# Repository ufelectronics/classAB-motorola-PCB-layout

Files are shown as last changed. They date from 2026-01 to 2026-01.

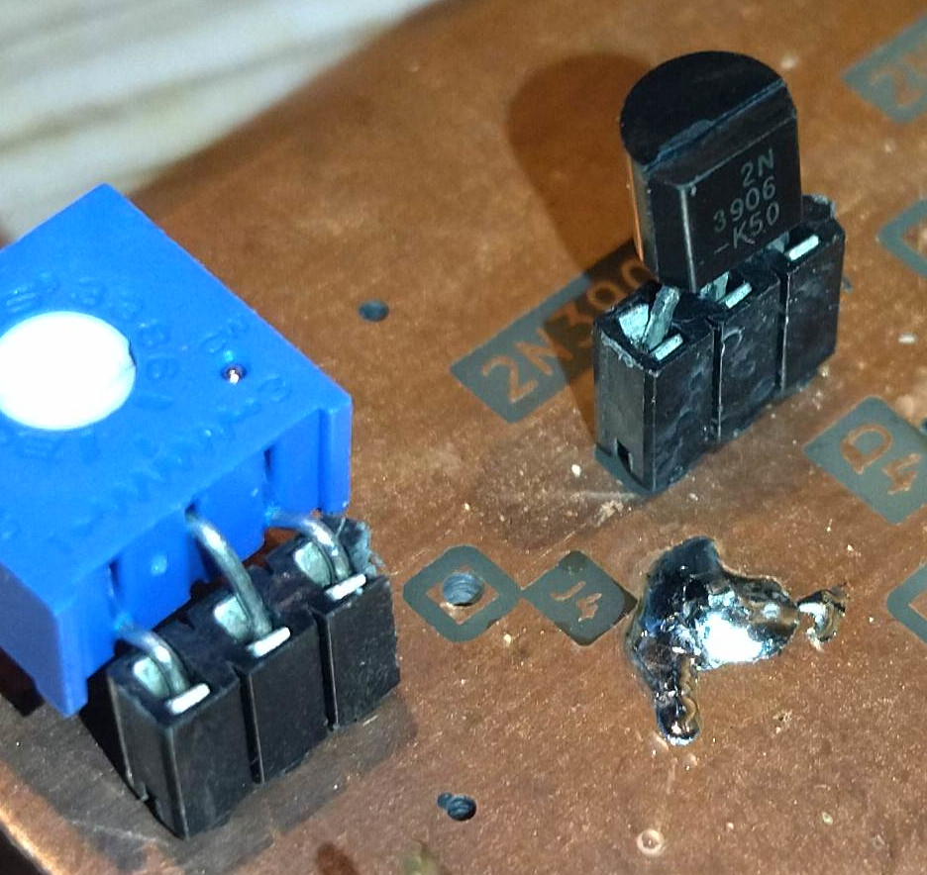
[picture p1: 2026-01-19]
classAB_motorola_PCB_layout/images/pin-header-example.jpg

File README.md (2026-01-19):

# classAB-motorola-PCB-layout

A PCB layout for making a experimental version yourself

# Motorola BJT Amp - Free KiCad Downloads

Build and experiment with the Motorola BJT Amp discussed on my profile back in November and December.

If you missed it, I once shared the KiCad file for simulating the Motorola AN-484A transistor amplifier.

Now I'm sharing the KiCad files for making a PCB yourself.

A The PCB includes:

* Integration of variable resistors (trimpots) - Make optimizations during testing - Faster results.

* Plenty of space around the components - Easier to measure at various points during testing.

* Through‑hole design, which makes it less demanding to build and therefore experiment‑ and beginner‑friendly.

* Schematic-Synchronized PCB Design - PCB design as it looks in the schematic, for easy mental switching.

This should guarantee easy experimentation, a fast outcome and way more fun. - An experience you'll never forget!

PRO TIP:

Use female pin headers at critical places instead of soldering the components directly onto the board. - This makes changes even easier and faster.

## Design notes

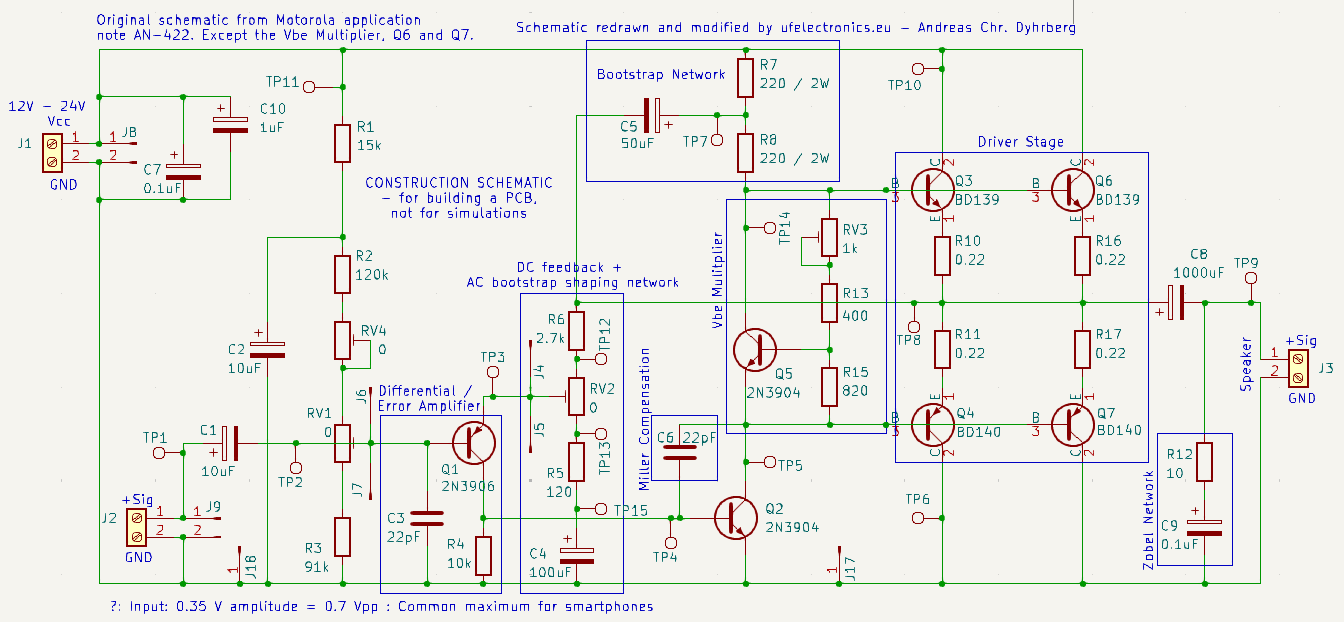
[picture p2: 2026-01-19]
classAB_motorola_PCB_layout/images/classAB_motorola_schematic_for_PCB_design.png

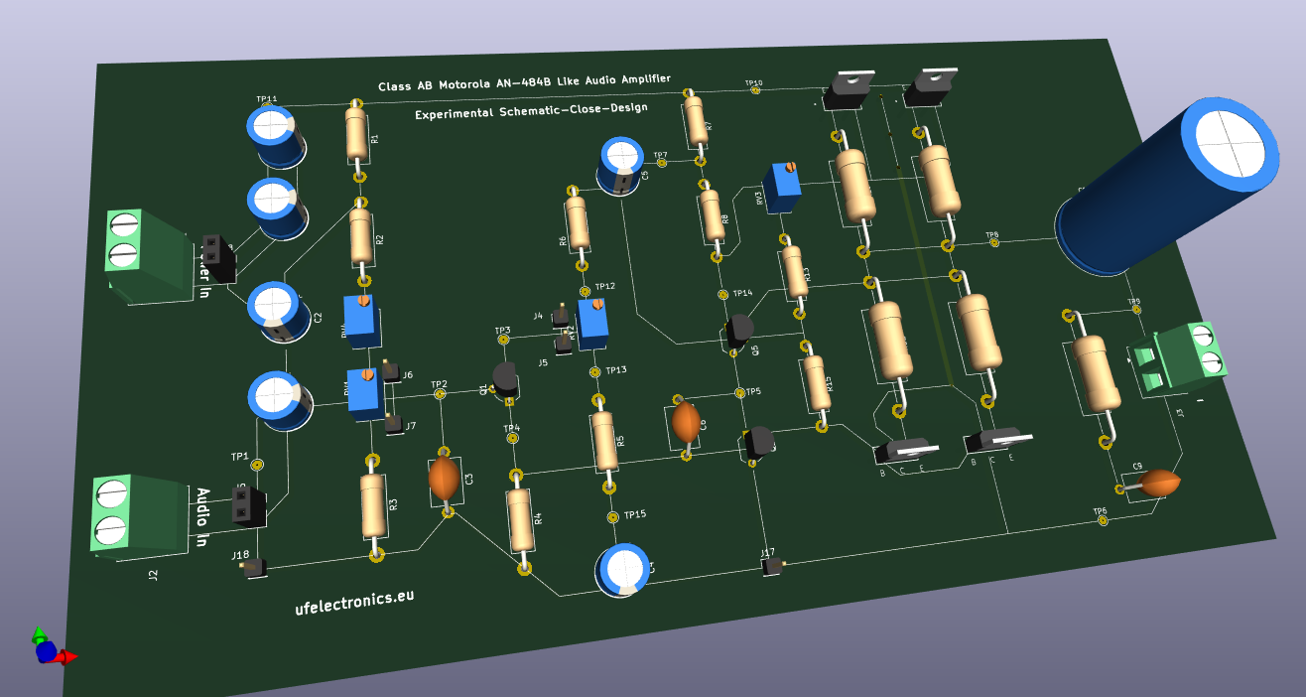
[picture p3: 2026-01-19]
classAB_motorola_PCB_layout/images/classAB_motorola_schematic_3D.png

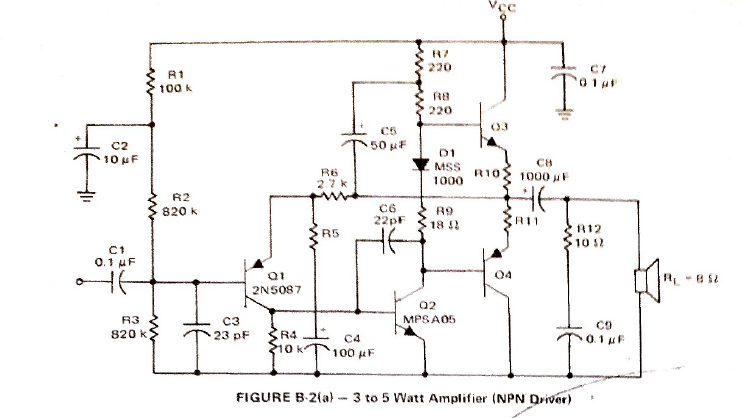
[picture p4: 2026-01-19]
classAB_motorola_PCB_layout/images/amplifier_Motorola_application_note_1764982252336.png

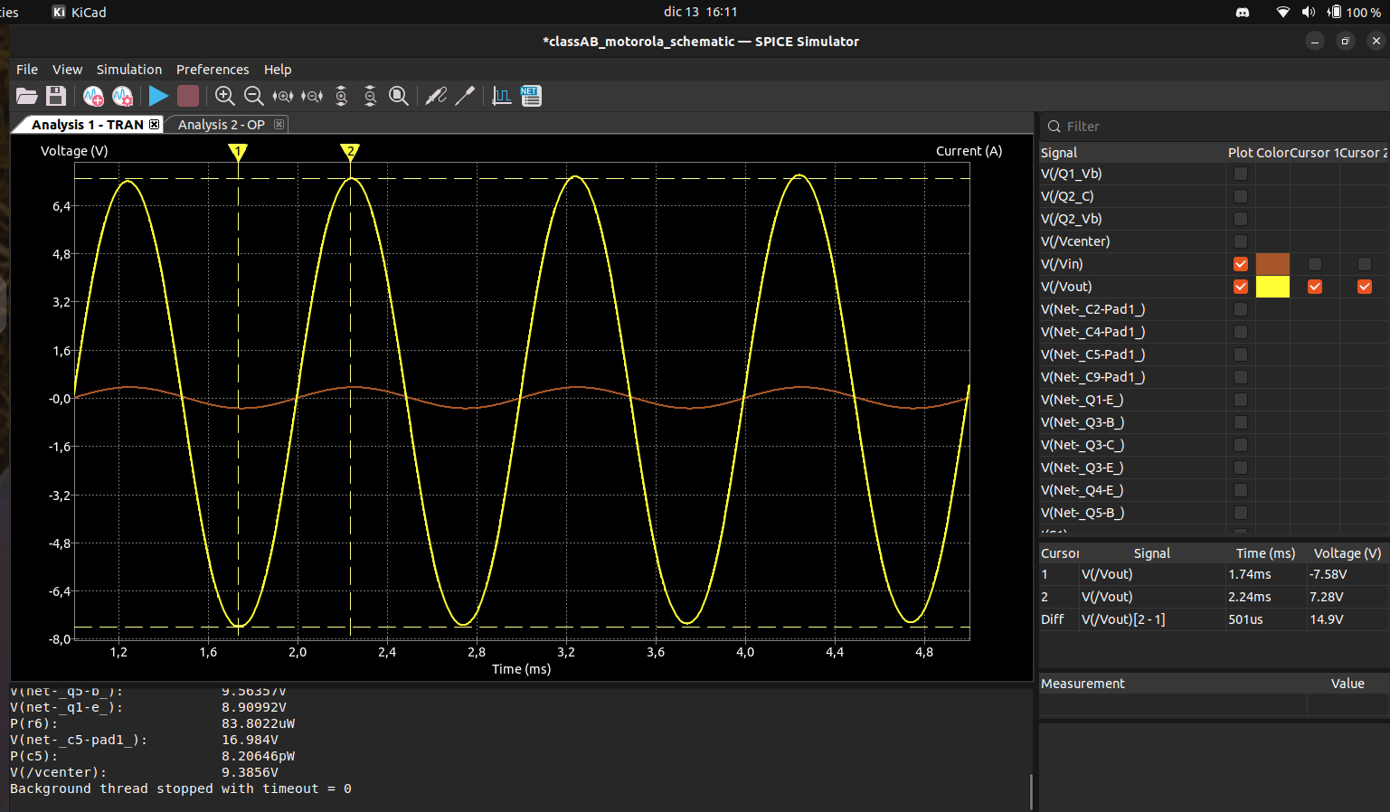
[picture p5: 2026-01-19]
classAB_motorola_PCB_layout/images/classAB_Motorola_AC_Sim_2025-12-13 16-11-28.png

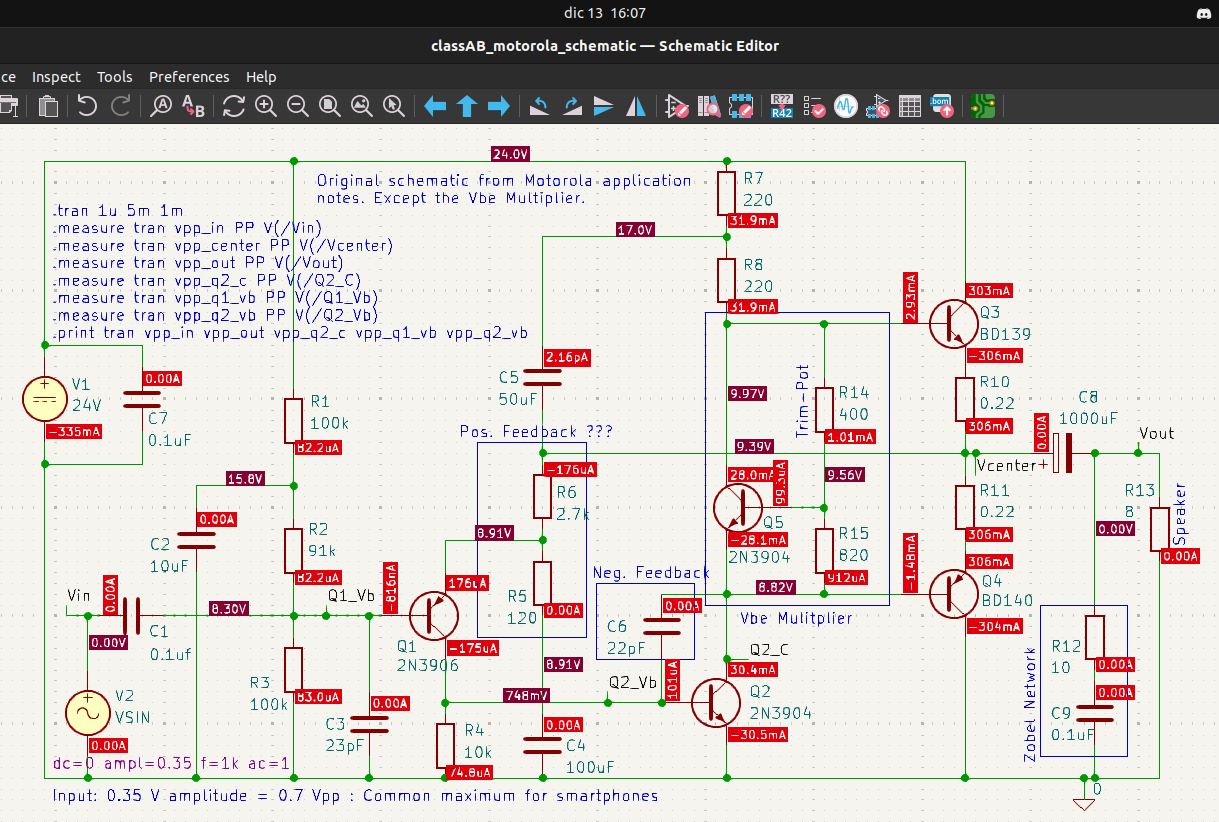
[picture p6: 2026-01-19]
classAB_motorola_PCB_layout/images/classAB_Motorola_DC_Sim_2025-12-13 16-07-55.png

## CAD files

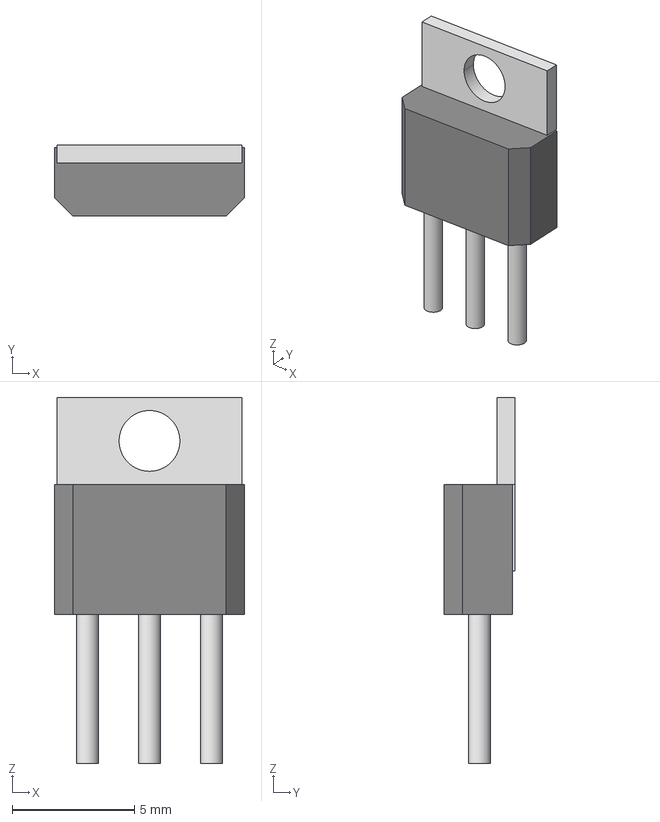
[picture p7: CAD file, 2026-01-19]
classAB_motorola_PCB_layout/BD139/SOT-32_STM.step
7.80 x 2.90 x 15.0 mm

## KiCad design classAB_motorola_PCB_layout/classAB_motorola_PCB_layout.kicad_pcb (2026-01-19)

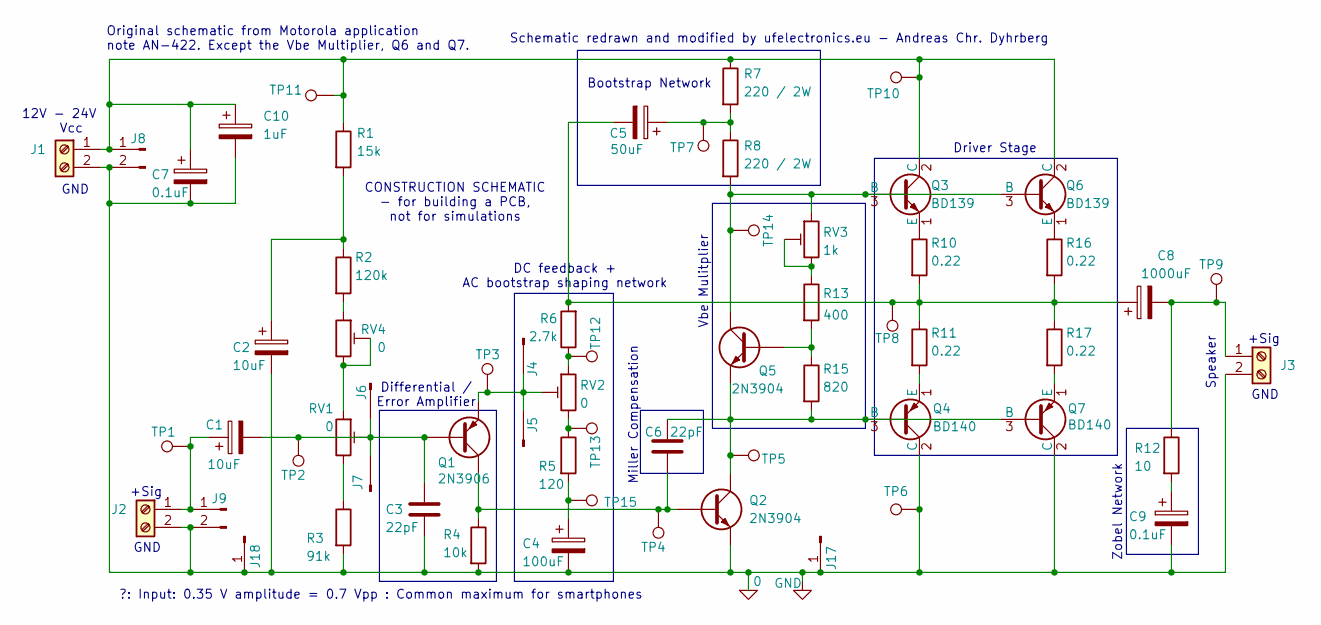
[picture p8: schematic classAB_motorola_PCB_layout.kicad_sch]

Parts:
C1, C2: 10uF; CP_Radial_D8.0mm_P5.00mm
C3, C6: 22pF; C_Disc_D7.5mm_W5.0mm_P10.00mm
C4: 100uF; CP_Radial_D8.0mm_P5.00mm
C5: 50uF; CP_Radial_D8.0mm_P5.00mm
C7: 0.1uF; CP_Radial_D8.0mm_P5.00mm
C8: 1000uF; C_Radial_D18.0mm_H35.5mm_P7.50mm
C9: 0.1uF; C_Disc_D7.5mm_W5.0mm_P10.00mm
C10: 1uF; CP_Radial_D8.0mm_P5.00mm
J1, J2, J3: Screw_Terminal_01x02; TerminalBlock_Phoenix_MKDS-1,5-2-5.08_1x02_P5.08mm_Horizont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
J4, J5, J6, J7, J17, J18: Conn_01x01_Pin; PinHeader_1x01_P2.54mm_Vertical
J8, J9: Conn_01x02_Pin; PinSocket_1x02_P2.54mm_Vertical
Q1: 2N3906; TO-92_Wide
Q2, Q5: 2N3904; TO-92_Wide
Q3, Q6: BD139; SOT-32_STM
Q4, Q7: BD140; SOT-32_STM
R1: 15k; R_Axial_DIN0411_L9.9mm_D3.6mm_P15.24mm_Horizontal
R2: 120k; R_Axial_DIN0411_L9.9mm_D3.6mm_P15.24mm_Horizontal
R3: 91k; R_Axial_DIN0411_L9.9mm_D3.6mm_P15.24mm_Horizontal
R4: 10k; R_Axial_DIN0411_L9.9mm_D3.6mm_P15.24mm_Horizontal
R5: 120; R_Axial_DIN0411_L9.9mm_D3.6mm_P15.24mm_Horizontal
R6: 2.7k; R_Axial_DIN0411_L9.9mm_D3.6mm_P15.24mm_Horizontal
R7, R8: 220 / 2W; R_Axial_DIN0411_L9.9mm_D3.6mm_P15.24mm_Horizontal
R10, R11, R16, R17: 0.22; R_Axial_DIN0614_L14.3mm_D5.7mm_P25.40mm_Horizontal
R12: 10; R_Axial_DIN0614_L14.3mm_D5.7mm_P25.40mm_Horizontal
R13: 400; R_Axial_DIN0411_L9.9mm_D3.6mm_P15.24mm_Horizontal
R15: 820; R_Axial_DIN0411_L9.9mm_D3.6mm_P15.24mm_Horizontal
RV1, RV2, RV4: 0; Potentiometer_Bourns_3266Y_Vertical
RV3: 1k; Potentiometer_Bourns_3266Y_Vertical
TP1, TP2, TP3, TP4, TP5, TP6, TP7, TP8, TP9, TP10, TP11, TP12, TP13, TP14, TP15: TestPoint; TestPoint_Pad_D1.5mm

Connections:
0: C2.2, C3.2, C4.2, C7.2, C9.2, C10.2, J1.2, J2.2, J3.2, J8.2, J9.2, J17.1, J18.1, Q2.3 (E), Q4.2 (C), Q7.2 (C), R3.2, R4.2, TP6.1
unnamed: C2.1, R1.2, R2.1
unnamed: C4.1, R5.2, TP15.1
unnamed: C5.1, R7.2, R8.1, TP7.1
unnamed: C5.2, C8.1, R6.2, R10.2, R11.1, R16.2, R17.1, TP8.1
unnamed: C9.1, R12.2
unnamed: C7.1, C10.1, J1.1, J8.1, Q3.2 (C), Q6.2 (C), R1.1, R7.1, TP10.1, TP11.1
unnamed: C1.1, J2.1, J9.1, TP1.1
unnamed: C8.2, J3.1, R12.1, TP9.1
unnamed: J4.1, J5.1, Q1.3 (E), RV2.2, TP3.1
unnamed: C1.2, C3.1, J6.1, J7.1, Q1.2 (B), RV1.2, TP2.1
unnamed: C6.2, Q1.1 (C), Q2.2 (B), R4.1, TP4.1
unnamed: C6.1, Q2.1 (C), Q4.3 (B), Q5.3 (E), Q7.3 (B), R15.2, TP5.1
unnamed: Q3.3 (B), Q5.1 (C), Q6.3 (B), R8.2, RV3.1, TP14.1
unnamed: Q3.1 (E), R10.1
unnamed: Q4.1 (E), R11.2
unnamed: Q5.2 (B), R13.2, R15.1
unnamed: Q6.1 (E), R16.1
unnamed: Q7.1 (E), R17.2
unnamed: R2.2, RV4.1
unnamed: R3.1, RV1.3
unnamed: R5.1, RV2.3, TP13.1
unnamed: R6.1, RV2.1, TP12.1
unnamed: R13.1, RV3.2, RV3.3
unnamed: RV1.1, RV4.2, RV4.3

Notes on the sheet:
GND
Zobel Network
?: Input: 0.35 V amplitude = 0.7 Vpp : Common maximum for smartphones
12V - 24V
+Sig
Bootstrap Network
Miller Compensation
Vcc
Differential / Error Amplifier
Speaker
CONSTRUCTION SCHEMATIC - for building a PCB, not for simulations
Original schematic from Motorola application note AN-422. Except the Vbe Multiplier, Q6 and Q7.
DC feedback + AC bootstrap shaping network
Vbe Mulitplier
Schematic redrawn and modified by ufelectronics.eu - Andreas Chr. Dyhrberg
Driver Stage

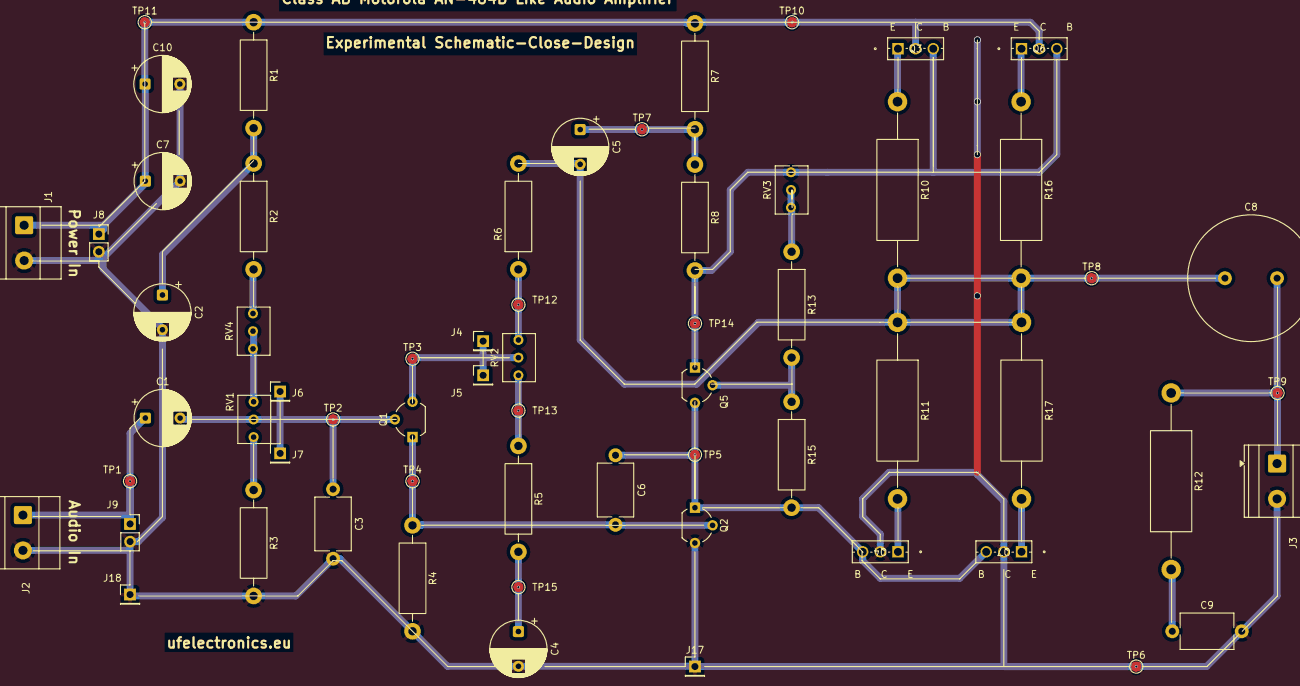
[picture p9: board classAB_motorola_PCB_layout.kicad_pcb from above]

Board: 2 copper layers, 62 parts (0 on the bottom side), 25 nets.
